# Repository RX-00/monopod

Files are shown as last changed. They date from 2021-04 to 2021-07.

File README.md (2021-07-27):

# monopod
WIP 2D monopod

SETUP VENV:
 1. If on a new platform w/o monopod/env then: python3 -m venv /path/to/new/virtual/environment
 2. don't forget to 'source monopod/env/bin/activate'
 3. then in the (env) pip3 install -e monopod
 4. don't forget to use setup.py w/ 'pip3 install .'

NOTE:
 - if the knee motor is not working despite no changes in hw and sw then do:
   1. complete power cycle
   2. run the move knee script
   3. retry
 - velocity command should be 0.0 if not specified, NOT math.nan!!

TODO:
- test out lcm py and cpp
    - create a make file for lcm
- maybe as the project evolves, use catkin to manage and build the project
- ADD AN ENCODER TO KNEE AND USE NEW FIRMWARE FEATURE ON MOTEUS CONTROLLER FOR REDUCTION UP GEAR RATIO
- set servo.position_min/max for moteus on lower level using command line tools or python diagnostic stream

BOM leg:
- moteus controller + test aluminium mount
- moteus brushless motor
- pi3hat for pi4 from mjbots
- pwr dist board r4.4 from mjbots
- TOPPROS 120XL SeriesWidth 3/8" 60 Teeth
- M3, M5 countersunk screws
- uxcell 6902-2RS Deep Groove Ball Bearing 15x28x7mm Double Sealed ABEC-3 Bearings

BOM testing rig:
- 2020 aluminium extrusion (100mm, 500mm)
- 2020 aluminium extrusion connectors, L brackets, screws, extension connectors, etc.
- 2020 linear ball bearing slider

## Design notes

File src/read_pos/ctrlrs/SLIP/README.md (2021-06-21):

SLIP Controller for the 2D monopod

TODO:
- IK
- Virtual Leg
- Raibert Controller

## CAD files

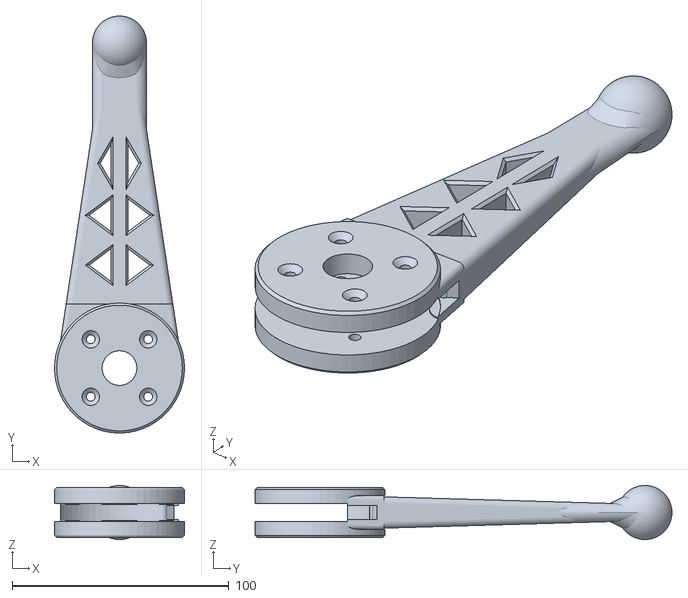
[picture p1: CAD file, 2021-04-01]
hw/Lower Leg.stl
60.0 x 192.4 x 25.0

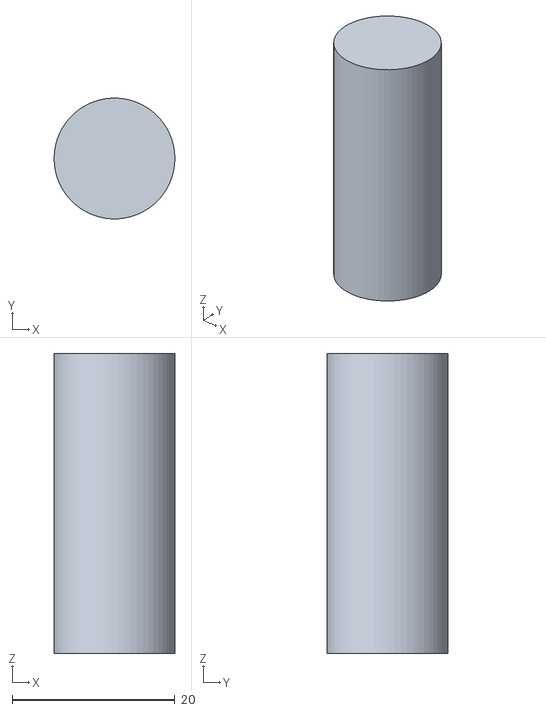
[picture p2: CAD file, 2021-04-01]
hw/Knee Dowel.stl
14.9 x 14.8 x 36.9

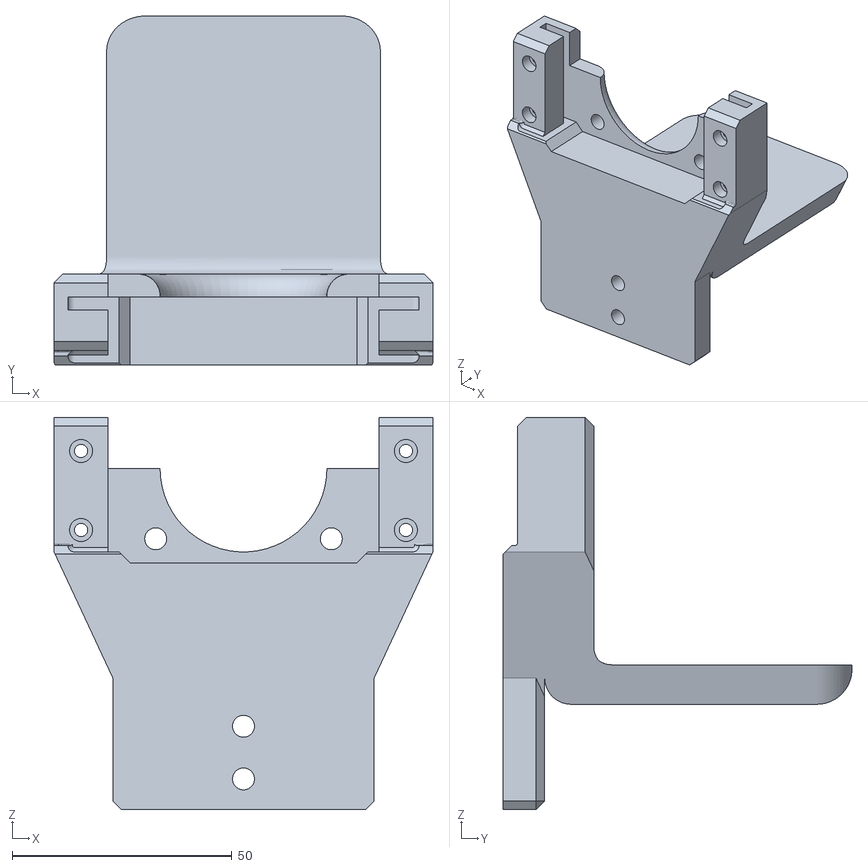
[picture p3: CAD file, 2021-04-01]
hw/Pitch Motor Mount 2020 Plate.stl
86.3 x 79.5 x 89.4

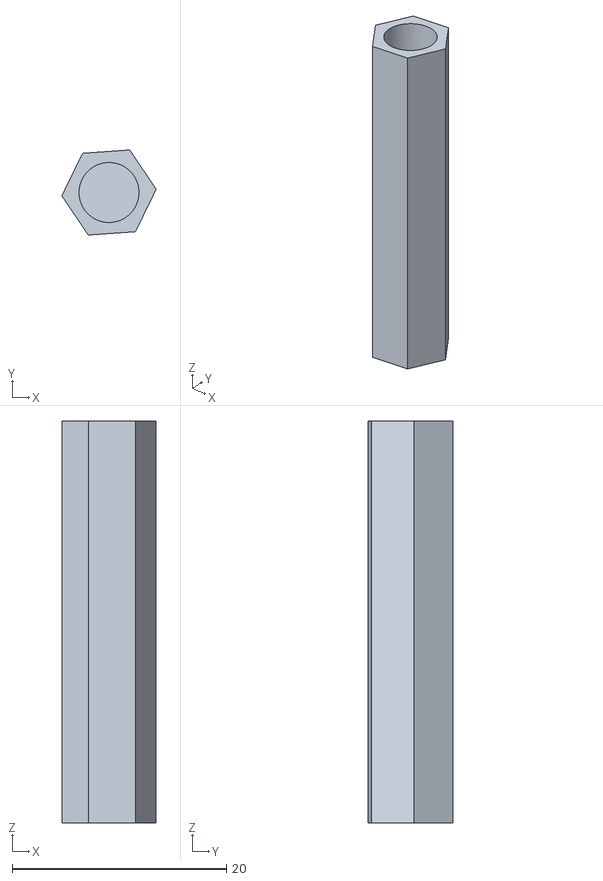
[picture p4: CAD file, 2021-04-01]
hw/Support Standoff.stl
8.82 x 7.95 x 37.5

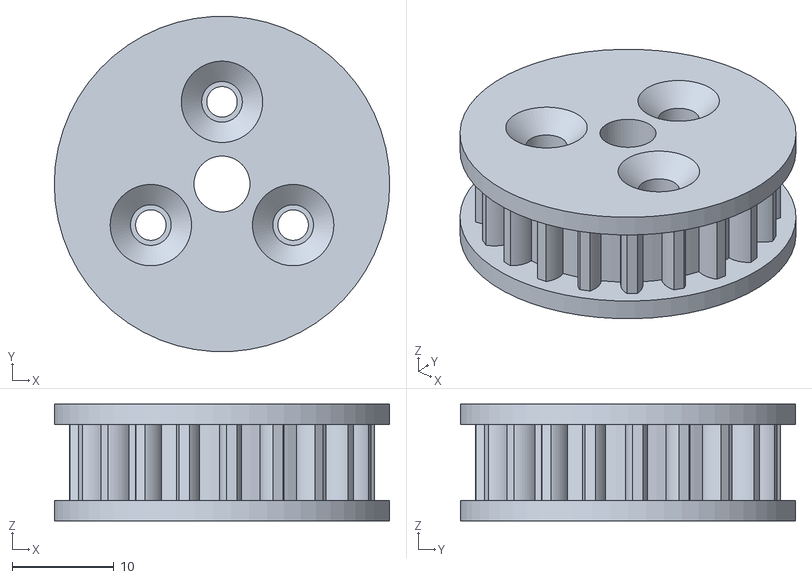
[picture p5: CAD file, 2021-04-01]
hw/Gear.stl
33.0 x 33.0 x 11.5

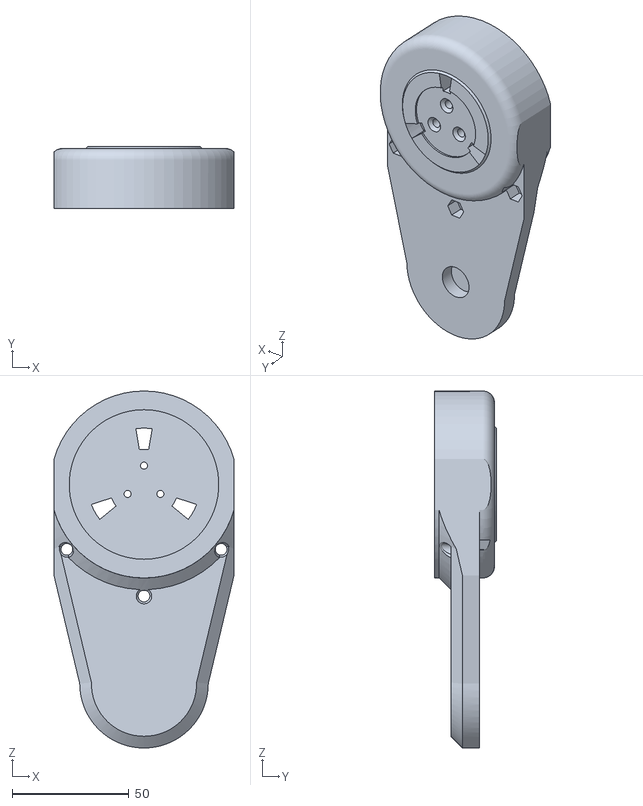
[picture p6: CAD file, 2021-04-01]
hw/Left Thigh Plate.stl
77.0 x 26.6 x 152.8

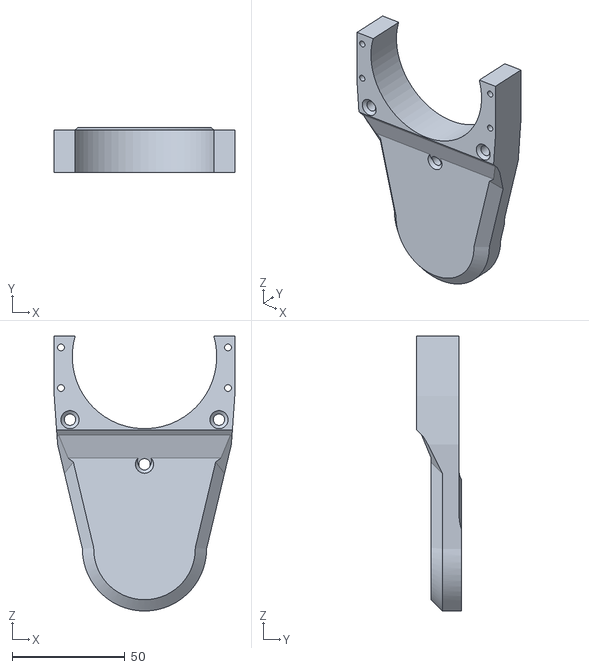
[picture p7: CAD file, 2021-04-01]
hw/Right Thigh Plate.stl
80.0 x 20.0 x 121.8

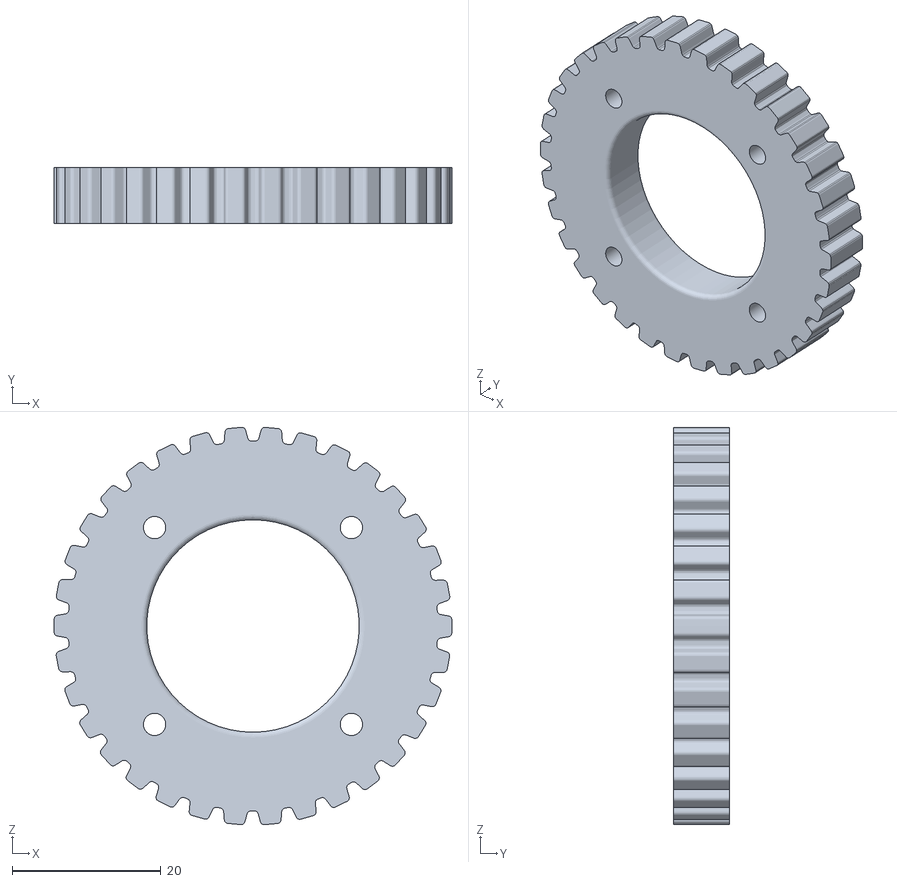
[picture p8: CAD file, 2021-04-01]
hw/Gear Knee.stl
53.6 x 7.50 x 53.5

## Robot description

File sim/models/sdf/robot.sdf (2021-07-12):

<sdf version="1.6">
<model name="onshape">
<link name="hip_gantry">
<frame name="hip_gantry_frame"><pose>0 0 0 0 -0 0</pose></frame>
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
<inertial>
<pose frame="hip_gantry_frame">-0.000155383 0.00657955 -0.0797081 0 0 0</pose>
<mass>8541.49</mass>
<inertia><ixx>2.47313</ixx><ixy>0.00234477</ixy><ixz>0.0243926</ixz><iyy>3.64943</iyy><iyz>-0.0560933</iyz><izz>1.22109</izz></inertia>
</inertial>
</link>

<link name="upper_leg">
<frame name="upper_leg_frame"><pose>0 0 0 0 -0 0</pose></frame>
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
<inertial>
<pose frame="upper_leg_frame">-0.000155294 0.0944062 -0.0602362 0 0 0</pose>
<mass>8542.05</mass>
<inertia><ixx>2.4756</ixx><ixy>-0.00231792</ixy><ixz>-0.0243347</ixz><iyy>3.65052</iyy><iyz>-0.0567427</iyz><izz>1.22276</izz></inertia>
</inertial>
</link>

<link name="trunk">
<pose>0 0 0 0 0 0</pose>
<inertial>
<pose>0 0 0 0 0 0</pose>
<mass>1e-9</mass>
<inertia>
<ixx>0</ixx><ixy>0</ixy><ixz>0</ixz><iyy>0</iyy><iyz>0</iyz><izz>0</izz>
</inertia>
</inertial>
</link>
<joint name="trunk_frame" type="fixed">
<pose>-0.000300936 0.0551195 -0.0696422 -1.59046e-15 -2.22045e-16 1.27492e-15</pose>
<parent>upper_leg</parent>
<child>trunk</child>
</joint>

<link name="lower_leg">
<frame name="lower_leg_frame"><pose>0 0 0 0 -0 0</pose></frame>
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
<inertial>
<pose frame="lower_leg_frame">-0.000360486 0.053723 -0.19761 0 0 0</pose>
<mass>0.151818</mass>
<inertia><ixx>0.000425068</ixx><ixy>5.49635e-12</ixy><ixz>-2.74466e-07</ixz><iyy>0.000447251</iyy><iyz>-3.2117e-08</iyz><izz>3.26309e-05</izz></inertia>
</inertial>
</link>

<link name="foot">
<pose>0 0 0 0 0 0</pose>
<inertial>
<pose>0 0 0 0 0 0</pose>
<mass>1e-9</mass>
<inertia>
<ixx>0</ixx><ixy>0</ixy><ixz>0</ixz><iyy>0</iyy><iyz>0</iyz><izz>0</izz>
</inertia>
</inertial>
</link>
<joint name="foot_frame" type="fixed">
<pose>-0.084562 0.0535695 -0.307388 3.14159 -1.11716e-15 -2.43876e-16</pose>
<parent>lower_leg</parent>
<child>foot</child>
</joint>

<joint name="knee" type="revolute">
<pose>-0.000300927 0.0652695 -0.154888 1.5708 -3.33067e-16 1.27013e-15</pose>
<parent>upper_leg</parent>
<child>lower_leg</child>
<axis>
<xyz>0 0 1</xyz>
<limit><effort>1</effort><velocity>20</velocity><lower>-2.0944</lower><upper>2.0944</upper></limit>
</axis>
</joint>

<joint name="hip" type="revolute">
<pose>-0.000300927 0.0158195 -0.070305 -1.5708 3.88578e-16 -3.14159</pose>
<parent>hip_gantry</parent>
<child>upper_leg</child>
<axis>
<xyz>0 0 1</xyz>
<limit><effort>1</effort><velocity>20</velocity><lower>1.48353</lower><upper>4.79966</upper></limit>
</axis>
</joint>


</model>
</sdf>

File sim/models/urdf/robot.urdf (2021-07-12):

<robot name="onshape">
<link name="hip_gantry">
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
<inertial>
<origin xyz="-0.000155383 0.00657955 -0.0797081" rpy="0 0 0"/>
<mass value="8541.49" />
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
</inertial>
</link>

<link name="upper_leg">
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
<inertial>
<origin xyz="-0.000145633 -0.0100688 -0.0785867" rpy="0 0 0"/>
<mass value="8542.05" />
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
</inertial>
</link>

<link name="trunk">
<inertial>
<origin xyz="0 0 0" rpy="0 0 0" />
<mass value="1e-9" />
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
</inertial>
</link>
<joint name="trunk_frame" type="fixed">
<origin xyz="9.18522e-09 -0.000662754 -0.0393" rpy="-1.5708 1.25445e-15 3.14159" />
<parent link="upper_leg" />
<child link="trunk" />
<axis xyz="0 0 0"/>
</joint>

<link name="lower_leg">
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
<inertial>
<origin xyz="-5.95589e-05 -0.0427225 0.0115465" rpy="0 0 0"/>
<mass value="0.151818" />
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
</inertial>
</link>

<link name="foot">
<inertial>
<origin xyz="0 0 0" rpy="0 0 0" />
<mass value="1e-9" />
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
</inertial>
</link>
<joint name="foot_frame" type="fixed">
<origin xyz="-0.084261 -0.1525 0.0117" rpy="1.5708 -1.51401e-15 7.84095e-16" />
<parent link="lower_leg" />
<child link="foot" />
<axis xyz="0 0 0"/>
</joint>

<joint name="knee" type="revolute">
<origin xyz="2.17762e-16 0.0845829 -0.04945" rpy="-1.4699e-15 1.24966e-15 3.14159" />
<parent link="upper_leg" />
<child link="lower_leg" />
<axis xyz="0 0 1"/>
<limit effort="1" velocity="20" lower="-2.0944" upper="2.0944"/>
<joint_properties friction="0.0"/>
</joint>

<joint name="hip" type="revolute">
<origin xyz="-0.000300927 0.0158195 -0.070305" rpy="-1.5708 3.88578e-16 -3.14159" />
<parent link="hip_gantry" />
<child link="upper_leg" />
<axis xyz="0 0 1"/>
<limit effort="1" velocity="20" lower="1.48353" upper="4.79966"/>
<joint_properties friction="0.0"/>
</joint>


</robot>

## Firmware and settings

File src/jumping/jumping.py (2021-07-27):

#!/usr/bin/python3 -B

# Sinusoidal jumping program for the 2D monopod setup

from ctrlrs.ik.sin_ik_hop_ctrlr import sinIkHopCtrlr
from moteus_ctrlr.src.two_d_leg_class import Leg

import numpy as np
import asyncio
import math
import moteus
import moteus_pi3hat
import time
import argparse
import sys



# TODO: check out and if needed tune/change the motor's internal PID
#       in order to increase damping!

knee = 1
hip  = 2

transport = moteus_pi3hat.Pi3HatRouter(
    servo_bus_map = {
        1:[knee], # KNEE
        2:[hip], # HIP
    },
)

servos = {
    servo_id : moteus.Controller(id=servo_id, transport=transport)
    for servo_id in [1, 2]
}

# NOTE: sin controller: Kp,  dt,   l0,  l1,  animation)
ctrlr = sinIkHopCtrlr(25.0, 0.015, 0.1, 0.15, False)
ctrlr_x = ctrlr_y = 0
theta0 = 0 # hip angle
theta1 = 0 # knee angle
commands = []
ctrlr.q[0] = 0 # x ft pos in sim
ctrlr.q[1] = 0 # y ft pos in sim


async def main():

    # clearing any faults
    await transport.cycle([x.make_stop() for x in servos.values()])

    # update the current pos to the closest one which is consistent with an output pos
    await servos[knee].set_rezero(0.0, query=True)
    await servos[hip].set_rezero(0.0, query=True)

    result_kn = result_hp = None
    while (result_hp and result_kn) is None:
        result_kn = await servos[knee].query()
        result_hp = await servos[hip].query()

    # now we have all the info about the actual monopod's joint positions,
    # so now we must convert & feedback that info to the ctrlr
    theta0 = ctrlr.convert_enc_rad_hp(result_hp.values[moteus.Register.POSITION])
    theta1 = ctrlr.convert_enc_rad_kn(result_kn.values[moteus.Register.POSITION])
    ctrlr_x, ctrlr_y = ctrlr.fwrd_kinematics(theta0, theta1)
    ctrlr.q[0] = ctrlr_x
    ctrlr.q[1] = ctrlr_y



    while True:
        now = time.time()
        # goal positions
        wave = np.sin(now)
        if (wave > 0):
            # crouch
            ctrlr.q[0] = 0.1
            ctrlr.q[1] =-0.15
            knee_pos = -0.175
            hip_pos = -0.065
        elif (wave < 0):
            # extend
            ctrlr.q[0] =-0.039
            ctrlr.q[1] = 0.039
            knee_pos = 0.387
            hip_pos = -0.244


        theta0, theta1 = ctrlr.two_link_leg_ik(
            des_eps=0.1, theta0=theta0, theta1=theta1)
        hp_pos = ctrlr.convert_rad_enc_hp(theta0)
        kn_pos = ctrlr.convert_rad_enc_kn(theta1)

        # irl position commands
        commands_irl = [
            servos[1].make_position( # KNEE
                position = ctrlr.convert_rad_enc_kn(kn_pos),
                velocity = 0.0,
                maximum_torque = 1.0,
                stop_position = math.nan,
                feedforward_torque = -0.01,
                watchdog_timeout = math.nan,
                query = True),
            servos[2].make_position( # HIP
                position = hip_pos,
                velocity = 0.0,
                maximum_torque = 1.0,
                stop_position = math.nan,
                feedforward_torque = -0.01,
                watchdog_timeout = math.nan,
                query = True),
        ]

        # sim position commands
        commands_sim = [
            servos[1].make_position( # KNEE
                position = ctrlr.convert_rad_enc_kn(kn_pos),
                #position = math.nan,
                velocity = 0.2,
                #velocity = 0.2 * math.sin(now),
                maximum_torque = 0.5,
                stop_position = math.nan,
                #stop_position = ctrlr.convert_rad_enc_kn(kn_pos),
                feedforward_torque = -0.01,
                watchdog_timeout = math.nan,
                query = True),
            servos[2].make_position( # HIP
                position = ctrlr.convert_rad_enc_hp(hp_pos),
                velocity = 0.2,
                #velocity = 0.2 * math.sin(now + 1),
                maximum_torque = 0.5,
                stop_position = math.nan,
                #stop_position = ctrlr.convert_rad_enc_hp(hp_pos),
                feedforward_torque = -0.01,
                watchdog_timeout = math.nan,
                query = True),
        ]

        results = await transport.cycle(commands_irl)

        # NOTE: it is possible to not receive responses from all servos
        #       for which a query was requested


        # We will wait 20ms between cycles. By default, each servo has
        # a watchdog timeout, where if no CAN command is received for
        # 100mc the controller will enter a latched fault state
        await asyncio.sleep(0.2)


async def main_bare():

    # clearing any faults
    await transport.cycle([x.make_stop() for x in servos.values()])

    while True:
        now = time.time()
        # goal positions
        wave = np.sin(now)
        if (wave > 0):
            # crouch
            knee_pos = -0.175
            hip_pos = -0.065
        elif (wave < 0):
            # extend
            knee_pos = -0.49
            hip_pos = -0.244

        # irl position commands
        commands_irl = [
            servos[1].make_position( # KNEE
                position = knee_pos,
                velocity = 2.0,
                maximum_torque = 0.5,
                stop_position = math.nan,
                feedforward_torque = -0.01,
                watchdog_timeout = math.nan,
                query = True),
            servos[2].make_position( # HIP
                position = hip_pos,
                velocity = 2.0,
                maximum_torque = 0.5,
                stop_position = math.nan,
                feedforward_torque = -0.01,
                watchdog_timeout = math.nan,
                query = True),
        ]
        results = await transport.cycle(commands_irl)

        # NOTE: it is possible to not receive responses from all servos
        #       for which a query was requested


        # We will wait 20ms between cycles. By default, each servo has
        # a watchdog timeout, where if no CAN command is received for
        # 100mc the controller will enter a latched fault state
        await asyncio.sleep(0.02)


if __name__ == "__main__":
    asyncio.run(main_bare())

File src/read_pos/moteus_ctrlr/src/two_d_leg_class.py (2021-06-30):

#!/usr/bin/python3 -B

# Jumping program for the 2D monoped setup
# This program should be extendable to add more servos (at later stages)
# such as, roll and yaw servos in the hip and also two ankle servos
# NOTE: ankle servos may end up being hobby servos (but this will be designed more in the future)
#

import asyncio
import math
import moteus
import moteus_pi3hat
import time
import argparse
import sys


'''
TODO:

REDO THIS WHOLE GODDAMN THING TO BE MORE LIKE ZERO_LEG.PY

Figure out how to make the spring jumping up and down virtual leg
1. get the measurements for the leg links
2. figure out the lowest possible length of the virtual leg spring
3. then figure out the IK that needs to be mapped to the input positions of the servos
   (This will be implemented as a cpp ctrlr that will interface with this py class)

'''


'''
NOTE: On the moteus controller these are the set position_min/max

KNEE servopos.position_min = -0.65
KNEE servopos.position_max = -0.15

HIP servopos.position_min = -0.51
HIP servopos.position_max = +0.02

KNEE id.id = 1
HIP  id.id = 2
'''


MAX_POS_KN = -0.15 - 0.00
MIN_POS_KN = -0.65 + 0.00

MAX_POS_HP =  0.02 - 0.00
MIN_POS_HP = -0.51 + 0.00




class Leg:
    # each arg corresponds to the respective servo CANBUS ID
    def __init__(self, knee, hip_pitch):
        self.knee = knee
        self.hip_pitch = hip_pitch

        # servo_bus_map arg describes which IDs are found on which bus
        self.transport = moteus_pi3hat.Pi3HatRouter(
            servo_bus_map = {
                1:[self.knee],
                2:[self.hip_pitch],
            },
        )
        # explicit servo_id's
        self.port_knee = 0
        self.port_hip_pitch = 1

        # create a moteus.Controller instance for each servo
        self.servos = {
            servo_id : moteus.Controller(id = servo_id, transport=self.transport)
            for servo_id in [1, 2] # number of motors, need to change manually
        }

        # commands for the motors, default set to mid values
        self.commands = [
            self.servos[self.knee].make_position(
                position = math.nan,
                velocity = 0.5,
                maximum_torque = 2.0,
                stop_position = (MAX_POS_KN - MIN_POS_KN) / 2,
                feedforward_torque = -0.01,
                watchdog_timeout = math.nan,
                query = True
            ),
            self.servos[self.hip_pitch].make_position(
                position = math.nan,
                velocity = 0.5,
                maximum_torque = 2.0,
                stop_position = (MAX_POS_HP - MIN_POS_HP) / 2,
                feedforward_torque = -0.01,
                watchdog_timeout = math.nan,
                query = True
            ),
        ]


    # send stop to clear faults && disable all the motors
    async def stop_all_motors(self):
        await self.transport.cycle([n.make_stop() for n in self.servos.values()])


    # set knee motor commands
    async def set_motor_kn_cmds(self, pos, vel, max_torq, stop_pos, ffwd_torq, watchdog_timeout, que):
        self.commands.insert(self.port_knee,
                             self.servos[self.knee].make_position(
                                 position = pos,
                                 velocity = vel,
                                 maximum_torque = max_torq,
                                 stop_position = stop_pos,
                                 feedforward_torque = ffwd_torq,
                                 watchdog_timeout = watchdog_timeout,
                                 query = que),
                             )


    # set hip motor commands
    async def set_motor_hp_cmds(self, pos, vel, max_torq, stop_pos, ffwd_torq, watchdog_timeout, que):
        self.commands.insert(self.port_hip_pitch,
                             self.servos[self.hip_pitch].make_position(
                                 position = pos,
                                 velocity = vel,
                                 maximum_torque = max_torq,
                                 stop_position = stop_pos,
                                 feedforward_torque = ffwd_torq,
                                 watchdog_timeout = watchdog_timeout,
                                 query = que),
                             )


    # send commands and return the results info
    async def send_motor_cmds(self):
        results = await self.transport.cycle(self.commands)
        return results




async def main():

    print("Starting jumping...")
    monopod = Leg(1, 2)
    # halfway position of each motorized joint
    kn_half = (MAX_POS_KN - MIN_POS_KN) / 2
    hp_half = (MAX_POS_HP - MIN_POS_HP) / 2

    # clearing any faults
    await monopod.stop_all_motors()
    print("cleared motor faults")

    while True:

        now = time.time()

        # testing the set commands
        await monopod.set_motor_kn_cmds(math.nan, 0.5, 2.0, MIN_POS_KN + kn_half + math.sin(now) * kn_half, -0.01, math.nan, True)
        await monopod.set_motor_hp_cmds(math.nan, 0.5, 2.0, MIN_POS_HP + hp_half + math.sin(now + 1) * hp_half, -0.01, math.nan, True)

        #print(monopod.commands[0])
        #print(monopod.commands[1])


        # test sending the commands
        results = await monopod.send_motor_cmds()

        # The result is a list of 'moteus.Result' types, each of which
        # identifies the servo it came from, and has a 'values' field
        # that allows access to individual register results.
        #
        # NOTE: it is possible to not receive responses from all servos
        #       for which a query was requested
        #
        # Here, we'll just print the ID, position, and velocity of each
        # servo for which a reply was returned
        '''print("".join(
            f"({result.id}) " +
            f"{result.values[moteus.Register.POSITION]} " +
            f"{result.values[moteus.Register.VELOCITY]} "
            for result in results
        ), end='\r')'''
        #print(now, end='\r')


        # await asyncio.sleep(0.5)



if __name__ == '__main__':
    asyncio.run(main())

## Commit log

2021-04-01 first hip pitch motor test
2021-04-01 added the stl's for the leg
    [Gear Knee.stl, Gear.stl, Knee Dowel.stl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]
2021-04-01 more generalized script for testing and setting configs for motors
2021-04-04 don't forget to power cycle after using tview, fixed some python path issues
    [gen_motor_position_testing.py, knee_pitch.py]
2021-04-06 need to write general servo move torque, pos, etc function
2021-05-09 started to work on pi3hat motor testing
2021-05-10 strange runtime error of not printing anything with pi3hat...
    [gen_motor_pos_pihat.py]
2021-05-17 make position calibration test and then test out gen_motor_pos_pihat.py
2021-06-13 let's just set calibrations with the visual tool
2021-06-15 velocity sinusoidal signal input to motors
2021-06-15 got the sinusoidal function and the limits working, but the hip motor isn't getting commands...
2021-06-17 turns out don't forget to set id.id through tview for each servo!
2021-06-19 now to figure out the math behind moving the virtual leg before I start writing more code
2021-06-19 time to test out the Leg class
2021-06-21 need to redo the whole Leg class based on mjbots' quad zero_leg.py
2021-06-21 actually not sure what's the most efficient way to implement the servos and legs classes
2021-06-28 still needing to learn some higher level stuff before being able to properly implement everything
    [config.txt]
2021-06-29 added some extra testing scripts for velocity control
2021-06-30 2d_leg_class-> maybe the await cycle is refreshing too fast for the transport cycle to keep up with?
    [gen_motor_pos_pihat.py, hip_pitch.py, knee_pitch.py]
2021-07-12 made sdf and urdf files
    [config.txt, robot.sdf, robot.urdf]
2021-07-13 getting used to the transition from MATLAB to numpy
    [robot.sdf, robot.urdf]
2021-07-19 need to start using the leg itself
2021-07-19 having some env issues again...
    [sin_hopping.py, two_d_leg_class.py, two_d_servo_class.py]
2021-07-19 just made the directory tree locally setup cuz the venv on raspberry pi is such a headache
2021-07-19 interpolated the conversion from radians to motor_pos in the sim and controllers
2021-07-19 need to create reverse conversion for enc pos and rad along with a better control loop for the controller to function in and test the read_pos program
    [sin_hopping.py]
2021-07-21 turns out 2.0 as max_torque was too much and 0.1 is too little?
    [sin_hopping.py]
2021-07-22 need some more work on representing irl correctly in sim
    [read_pos.py, sin_hopping.py]
2021-07-22 time to get irl and sim translated correctly together
    [read_pos.py]
2021-07-22 a little more fixing on the knee conversion
    [read_pos.py]
2021-07-22 REWRITE THE HOPPING FUNCTION WITHOUT THE LEG CLASS AND ALSO MAKE IT SO THAT IT MORE CLOSELY FUNCTIONS LIKE THE SIN ANIMATION, CUZ THOSE IRL POSITIONS ARE CONVERTED STRANGELY
2021-07-23 made progress on moving leg to jump, but knee won't move... time to do some raw simple testing with main_bare() in jumping.py
    [disable_stop_motors.py, gen_motor_pos_pihat.py, gen_motor_position_testing.py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]
2021-07-25 don't forget the ethernet when power cycling
2021-07-29 fixed up the knee limits and calibration, take note and change anything you come across for the old knee configs
